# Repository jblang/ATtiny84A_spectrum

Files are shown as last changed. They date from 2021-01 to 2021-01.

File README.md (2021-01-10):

## ATtiny Spectrum Analyzer

This is an 8-channel spectrum analyzer using ATtiny84A and an electret microphone.  The 20x gain stage of the differential ADC is used so a separate amplifier is not necessary.

The code uses a DFT algorithm by Łukasz Podkalicki.  Original code was based on his [blog post](https://blog.podkalicki.com/attiny13-disco-lights-using-dft/), but after I contacted him he kindly shared a newer version of the code which I don't believe he had published previously.  I adapted the newest code to the ATtiny84A with 8 channels and tweaked the thresholds to work with an electret microphone.

The code for an earlier experiment with the ATtiny13A is also included. The 13A doesn't include a gain stage on it's ADC so a LM386 audio amplifier was used to amplify the audio signal before passing it into the 13's ADC.

I have also designed a PCB for the ATtiny84A version but I haven't had it manufactured yet.

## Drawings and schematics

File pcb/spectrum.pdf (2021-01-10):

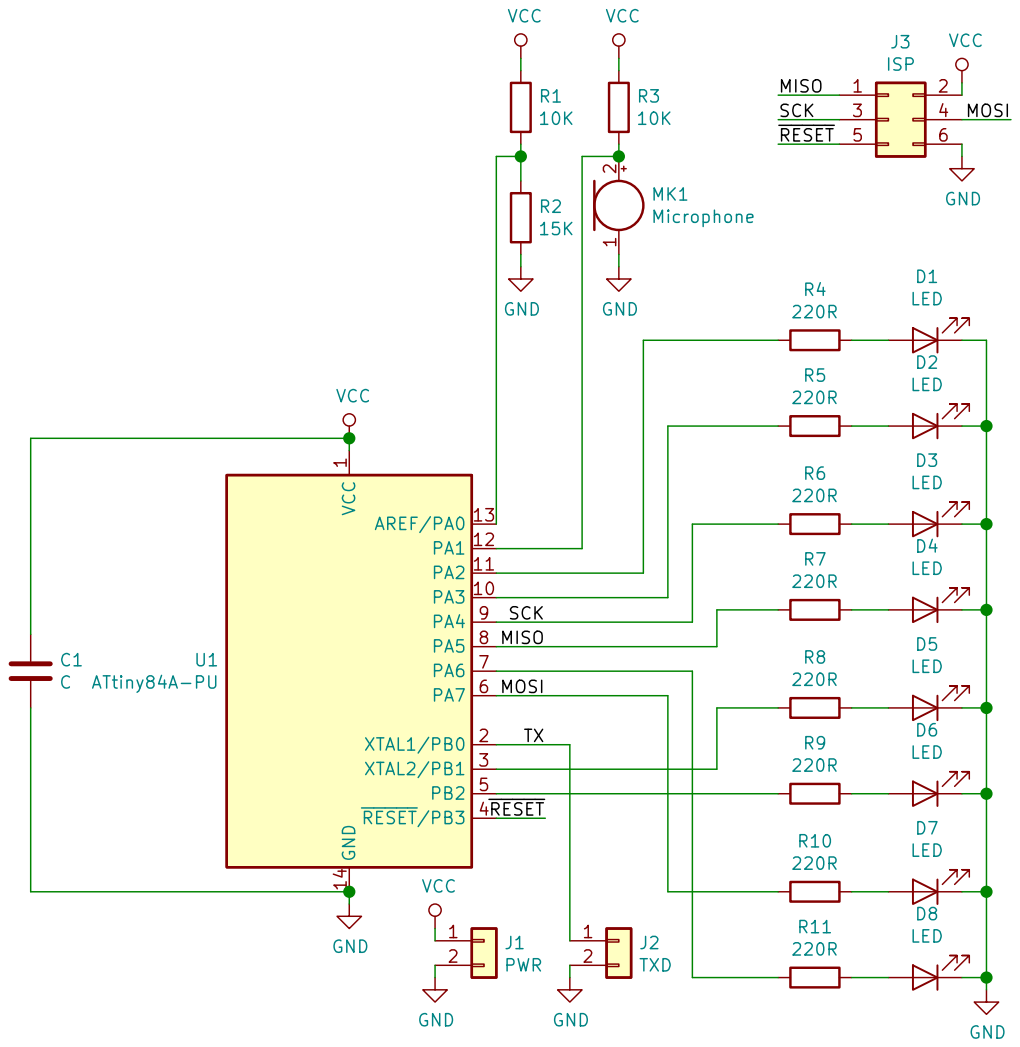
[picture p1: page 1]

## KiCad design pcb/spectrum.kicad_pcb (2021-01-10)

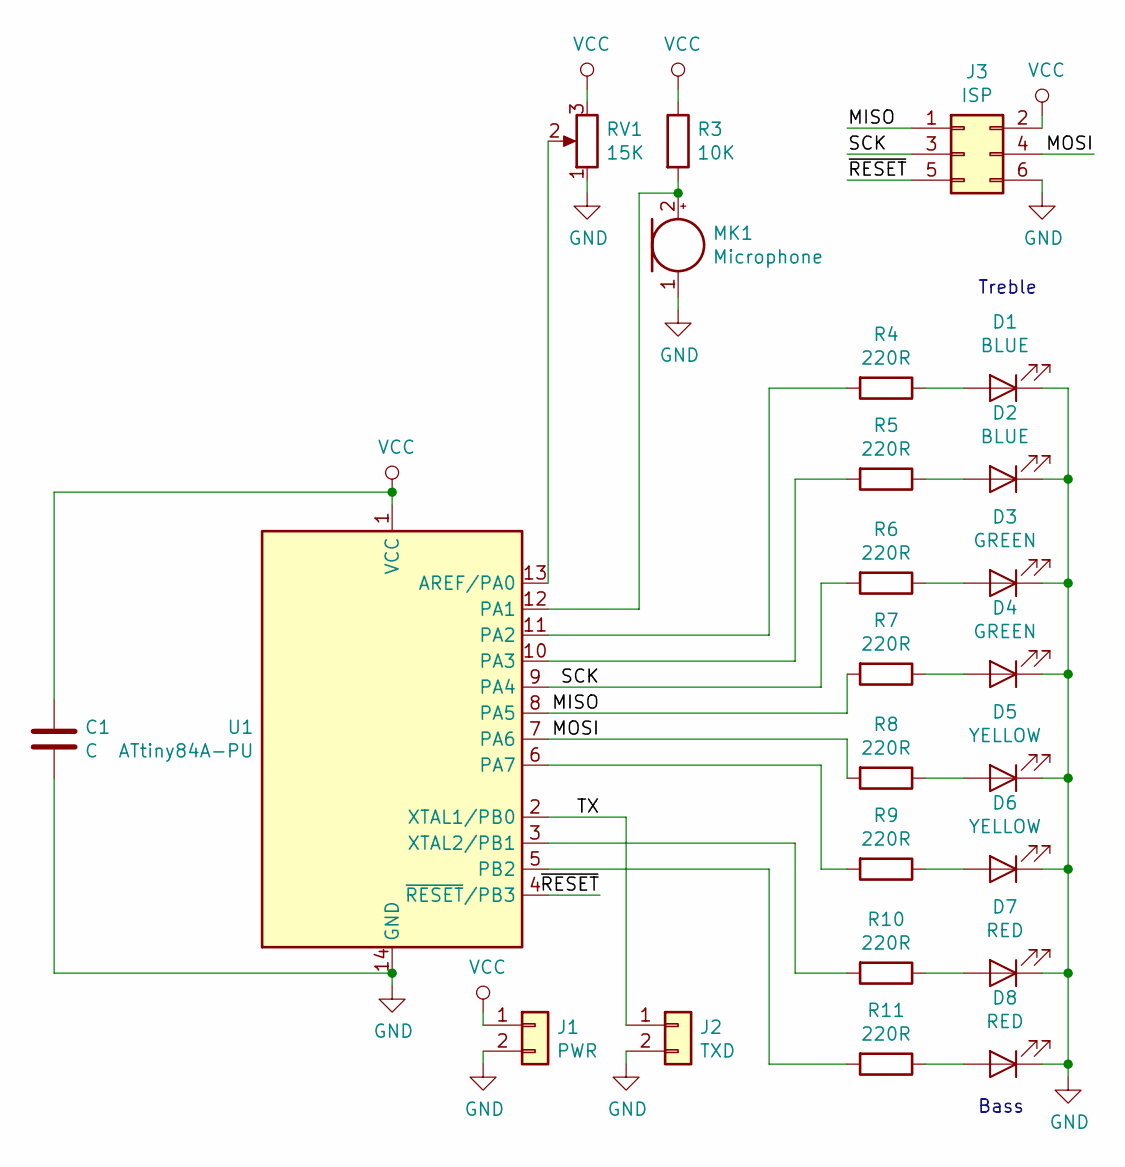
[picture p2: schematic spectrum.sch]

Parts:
C1: C; C_Disc_D3.0mm_W1.6mm_P2.50mm
D1, D2: BLUE; LED_D3.0mm
D3, D4: GREEN; LED_D3.0mm
D5, D6: YELLOW; LED_D3.0mm
D7, D8: RED; LED_D3.0mm
J1: PWR; PinHeader_1x02_P2.54mm_Horizontal
J2: TXD; PinHeader_1x02_P2.54mm_Horizontal
J3: ISP; PinHeader_2x03_P2.54mm_Horizontal
MK1: Microphone; PinHeader_1x02_P2.54mm_Vertical
R3: 10K; R_Axial_DIN0207_L6.3mm_D2.5mm_P7.62mm_Horizontal
R4, R5, R6, R7, R8, R9, R10, R11: 220R; R_Axial_DIN0207_L6.3mm_D2.5mm_P7.62mm_Horizontal
RV1: 15K; Potentiometer_Bourns_3296P_Horizontal
U1: ATtiny84A-PU; DIP-14_W7.62mm

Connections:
/MISO: J3.1, R7.2, U1.8 (PA5)
/MOSI: J3.4, R8.2, U1.7 (PA6)
/SCK: J3.3, R6.2, U1.9 (PA4)
/TX: J2.1, U1.2 (XTAL1/PB0)
/~RESET: J3.5, U1.4 (~RESET~/PB3)
GND: C1.2, D1.1 (K), D2.1 (K), D3.1 (K), D4.1 (K), D5.1 (K), D6.1 (K), D7.1 (K), D8.1 (K), J1.2, J2.2, J3.6, MK1.1 (-), RV1.1, U1.14 (GND)
unnamed: D1.2 (A), R4.1
unnamed: D2.2 (A), R5.1
unnamed: D3.2 (A), R6.1
unnamed: D4.2 (A), R7.1
unnamed: D5.2 (A), R8.1
unnamed: D6.2 (A), R9.1
unnamed: D7.2 (A), R10.1
unnamed: D8.2 (A), R11.1
unnamed: MK1.2 (+), R3.2, U1.12 (PA1)
unnamed: R4.2, U1.11 (PA2)
unnamed: R5.2, U1.10 (PA3)
unnamed: R9.2, U1.6 (PA7)
unnamed: R10.2, U1.3 (XTAL2/PB1)
unnamed: R11.2, U1.5 (PB2)
unnamed: RV1.2, U1.13 (AREF/PA0)
VCC: C1.1, J1.1, J3.2, R3.1, RV1.3, U1.1 (VCC)

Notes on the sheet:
Treble
Bass

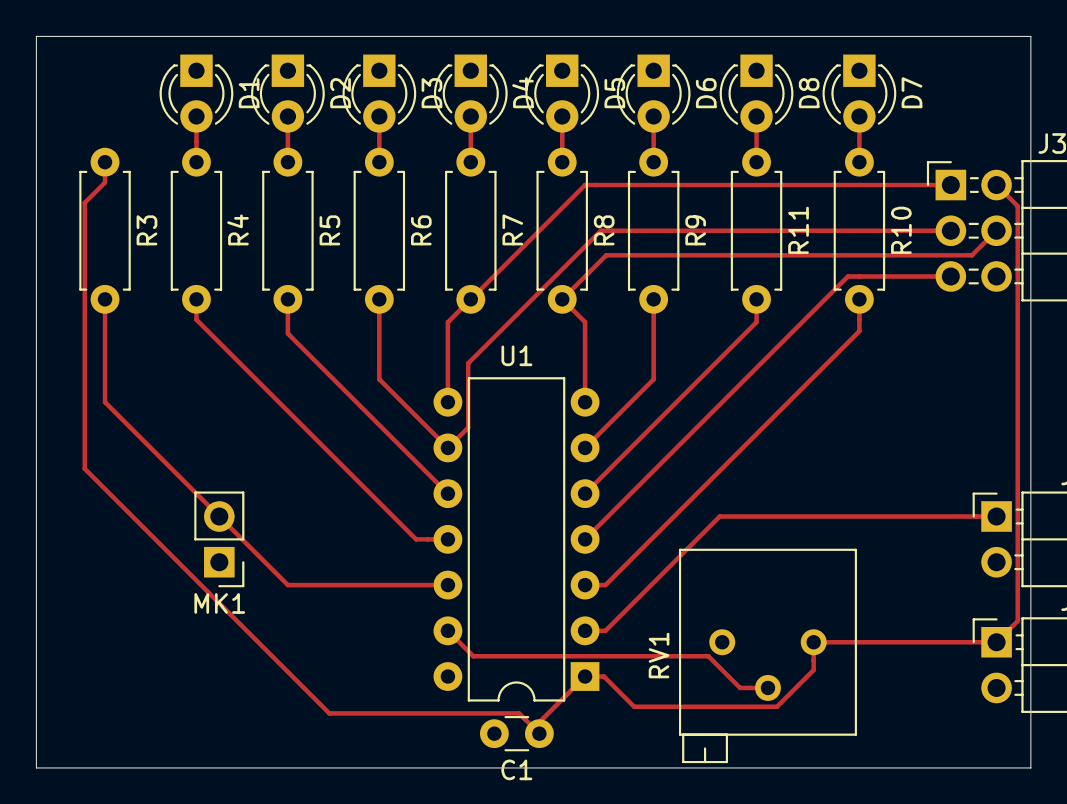
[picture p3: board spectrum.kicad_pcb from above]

Board: 2 copper layers, 55.2 x 40.6 mm, 24 parts (0 on the bottom side), 22 nets.

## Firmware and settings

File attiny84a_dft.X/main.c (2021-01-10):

#define F_CPU 8000000

#include <avr/io.h>
#include <avr/interrupt.h>
#include <util/delay.h>
#include <math.h>
#include <stdlib.h>

// UART pins
#define TX_PORT     PORTB
#define TX_PIN      PB0
#define TX_DDR      DDRB
#define TX_DDR_PIN  DDB0

volatile uint16_t txbyte = 0;

void uart_putchar(char c) {
    while (txbyte)
        ;
    txbyte = (c << 1) | (1 << 9); // char + stop bit
    TCCR0B = (1 << CS01);
}

void uart_putstr(char* string) {
    while (*string)
        uart_putchar(*string++);
}

void uart_init() {
    TX_DDR |= (1 << TX_DDR_PIN);
    TX_PORT |= (1 << TX_PIN);
    TCCR0A = (1 << WGM01); // CTC mode
    TIMSK0 |= (1 << OCF0A);
    OCR0A = 103; // 104 us (9600 baud ) @ 1 MHz timer clock
    sei();
}

ISR(TIM0_COMPA_vect) {
    uint16_t local_txbyte = txbyte;
    if (local_txbyte & 1)
        TX_PORT |= (1 << TX_PIN);
    else
        TX_PORT &= ~(1 << TX_PIN);
    local_txbyte >>= 1;
    txbyte = local_txbyte;
    if (!local_txbyte) {
        TCCR0B = 0;
        TCNT0 = 0;
    }
}

#define N           32
#define PI2         6.2832
#define TFS         6
#define NUM_LEDS    8
#define BANK_MAX    16
#define THRESHOLD   0U
#define OFFSET      0

static int8_t samples[N]; // discrete-time signal
static int16_t W[N]; // Twiddle Factors
static uint16_t power[NUM_LEDS + 1]; // power spectrum of x
static uint8_t bank[NUM_LEDS]; // flash accumulation
static const uint8_t pins[NUM_LEDS] = {0x11, 0x12, 0x07, 0x06, 0x05, 0x04, 0x03, 0x02};

volatile uint8_t counter = 0; // samples counter

void
dft(void) {
    int32_t Xre, Xim;
    uint8_t sin_idx, cos_idx;
    
    power[NUM_LEDS] = 0;

    for (uint8_t k = 0; k < N / 2 + 1; ++k) {
        Xre = Xim = 0;
        cos_idx = 0;
        sin_idx = 3 * N / 4;
        for (uint8_t n = 0; n < N; ++n) {
            Xre += ((int) samples[n] * (int) W[cos_idx % N]) >> TFS;
            Xim -= ((int) samples[n] * (int) W[sin_idx % N]) >> TFS;
            sin_idx += k;
            cos_idx += k;
        }
        uint16_t p = (Xre * Xre + Xim * Xim) / (N * N);
        if (k > NUM_LEDS)
            power[NUM_LEDS] = p;
        else
            power[k] = p;
    }
}

void
kolorofon(void) {
    for (uint8_t i = 0; i < NUM_LEDS; ++i) {
        if (power[i + 1] > THRESHOLD) {
            if (bank[i] < BANK_MAX) {
                bank[i]++;
            }
            if (pins[i] & 0xf0)
                PORTB |= _BV(pins[i] & 0xf);
            else
                PORTA |= _BV(pins[i] & 0xf);
        } else {
            if (bank[i]) {
                bank[i]--;
            } else {
                if (pins[i] & 0xf0)
                    PORTB &= ~_BV(pins[i] & 0xf);
                else
                    PORTA &= ~_BV(pins[i] & 0xf);
            }
        }
    }
}

ISR(ADC_vect) {

    if (counter < N) {
        samples[counter++] = ADCH; // read raw sample <-128; 127>

        ADCSRA |= _BV(ADSC); // trigger next signal acquisition
    }
}

void adc_init(void) {
    ADCSRA |= _BV(ADPS2) | _BV(ADPS1); // 8 MHz / 64 = 125 khz ADC clock
    ADCSRA |= _BV(ADEN) | _BV(ADIE); // enable ADC interrupt
    ADCSRB |= _BV(BIN) | _BV(ADLAR); // left adjust, bipolar mode
    ADMUX =  _BV(MUX3) | _BV(MUX0); // differential ADC0/1 20x gain
}

void log_power(void)
{
    for (uint8_t i = 0; i < N >> 1; i++) {
        char buf[16];
        utoa(power[i], buf, 10);
        uart_putstr(buf);
        uart_putchar('\t');
    }
    uart_putchar('\n');
    uart_putchar('\r');
}

void log_samples(void)
{
    for (uint8_t i = 0; i < N; i++) {
        char buf[16];
        itoa(samples[i], buf, 10);
        uart_putstr(buf);
        uart_putchar('\t');
    }
    uart_putchar('\n');
    uart_putchar('\r');
}

int main(void) {
    DDRB |= _BV(PB2) | _BV(PB1);
    DDRA |= _BV(PA7) | _BV(PA6) | _BV(PA5) | _BV(PA4) | _BV(PA3) | _BV(PA2);

    adc_init();
    uart_init();
    sei();

    ADCSRA |= _BV(ADSC);

    /* generate Twiddle Factors */
    for (uint8_t n = 0; n < N; ++n) {
        W[n] = (int16_t) ((float) (1 << TFS) *
                cos((float) n * PI2 / (float) N));
    }

    while (1) {
        if (counter == N) {
            dft();
            //log_power();
            //log_samples();
            kolorofon();
            counter = 0;
            ADCSRA |= _BV(ADSC);
        }
    }
}

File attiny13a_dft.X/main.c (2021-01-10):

#define F_CPU 9600000

/**
 * Copyright (c) 2019, Lukasz Marcin Podkalicki <lpodkalicki@gmail.com>
 * ATtiny13/026
 * Disco lights using DFT (Discrete Fourier Transformation)
 */

#include <avr/io.h>
#include <avr/interrupt.h>

#define LED_LOW              PB1
#define LED_MID              PB2
#define LED_HIGH             PB0

#define LOW_THRESHOLD        (65500UL)
#define MID_THRESHOLD        (500)
#define HIGH_THRESHOLD       (5000)

#define N                    (7) // N-points (DFT)
#define B                    (3 * N / 4) // b-value (DFT)

const int8_t W[N] = {10, 6, -2, -9, -9, -2, 6}; // twiddle factors (DFT)
int8_t samples[N]; // raw samples (ADC)
uint16_t power[N >> 1]; // power spectrum (DFT)
volatile uint8_t counter = 0;

static void dft(void);

int
main(void) {

    /* setup */
    DDRB |= _BV(LED_LOW) | _BV(LED_MID) | _BV(LED_HIGH); // set LED pins as OUTPUT
    ADCSRA |= _BV(ADPS2) | _BV(ADPS1); // set ADC division factor to 256
    ADCSRA |= _BV(ADEN) | _BV(ADIE); // enable ADC interrupt
    ADMUX = _BV(MUX1); // set ADC4 (PB4) as audio input
    ADMUX |= _BV(ADLAR); // left adjust of ADC result
    sei(); // enable global interrupts

    ADCSRA |= _BV(ADSC); // start first signal acquisition

    /* loop */
    while (1) {
        if (counter == N) {
            dft(); // do some DSP

            /* LOW freqency band */
            if (~power[0] > LOW_THRESHOLD) {
                PORTB |= _BV(LED_LOW);
            } else {
                PORTB &= ~_BV(LED_LOW);
            }

            /* MID freqency band */
            if (power[1] > MID_THRESHOLD) {
                PORTB |= _BV(LED_MID);
            } else {
                PORTB &= ~_BV(LED_MID);
            }

            /* HIGH frequency band */
            if (power[2] > HIGH_THRESHOLD) {
                PORTB |= _BV(LED_HIGH);
            } else {
                PORTB &= ~_BV(LED_HIGH);
            }

            counter = 0; // reset samples counter
            ADCSRA |= _BV(ADSC); // trigger next signal acqusistion
        }
    }
}

ISR(ADC_vect) {

    if (counter < N) {
        samples[counter++] = ADCH - 128; // read raw sample <-128; 127>
        ADCSRA |= _BV(ADSC); // trigger next signal acquisition
    }
}

/**
 * Twiddle-factor-based DFT algorithm with reduced memory access.
 */
void
dft(void) {
    uint8_t a, b, i, j;
    int16_t re[N];
    int16_t im[N];

    for (i = 0; i < N; ++i) {
        re[i] = 0;
        im[i] = 0;
    }

    for (i = 0; i < (N >> 1); ++i) {
        a = 0;
        b = B;
        for (j = 0; j < N; ++j) {
            re[i] += W[a % N] * samples[j];
            im[i] -= W[b % N] * samples[j];
            a += i;
            b += i;
        }
        power[i] = (re[i] * re[i] + im[i] * im[i]) >> 4;
    }
}
